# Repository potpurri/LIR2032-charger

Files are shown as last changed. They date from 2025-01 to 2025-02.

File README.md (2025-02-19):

# LIR2032 Battery Charging Board

## Overview

Charging board for LIR2032 batteries (or other lithium type button/coin cell batteries with the same diameter and max voltage of 4.2V).

This project features a charging board for LIR2032 batteries. It uses a TP4056 to monitor charging and provides options for safety components. The circuit includes components to manage the charging process efficiently and safely.

Completed PCBs:

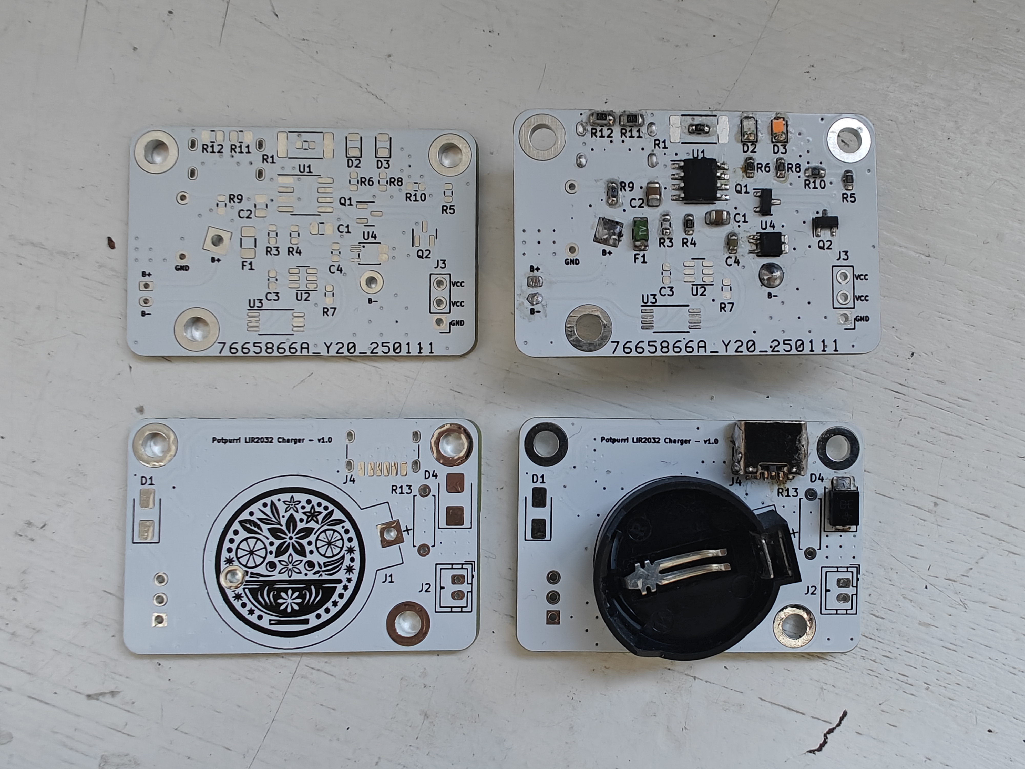
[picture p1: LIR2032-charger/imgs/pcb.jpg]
PCB


## Features

The board includes the following components:

- **TP4056**: For monitoring the charging process.
- **Safety options**: Can use either a DW01A and a FS8205A or a XB7608AJ for safety.
- **P-MOSFETs**: Two P-MOSFETs cut the connection between the battery and the load during charging (if a load is connected to the charging board).
- **Schottky Diode**: Available to forward current from the USB-C charging input to the load during charging.
- **Charging Current Settings (Resistor R9)**: The resistor R9 is used to set the charging current with the following correlations:

| Resistor (Ω) | Charging Current (mA) |
|---|---|
| 10k | 120 |
| 12k | 100 |
| 15k | 80.0 |
| 18k | 66.7 |
| 22k | 54.5 |
| 27k | 44.4 |
| 33k | 36.4 |
| 39k | 30.8 |
| 47k | 25.5 |
| 56k | 21.4 |
| 68k | 17.6 |
| 82k | 14.6 |
| 100k | 12.0 |

Board being charged with approximately 37mA:

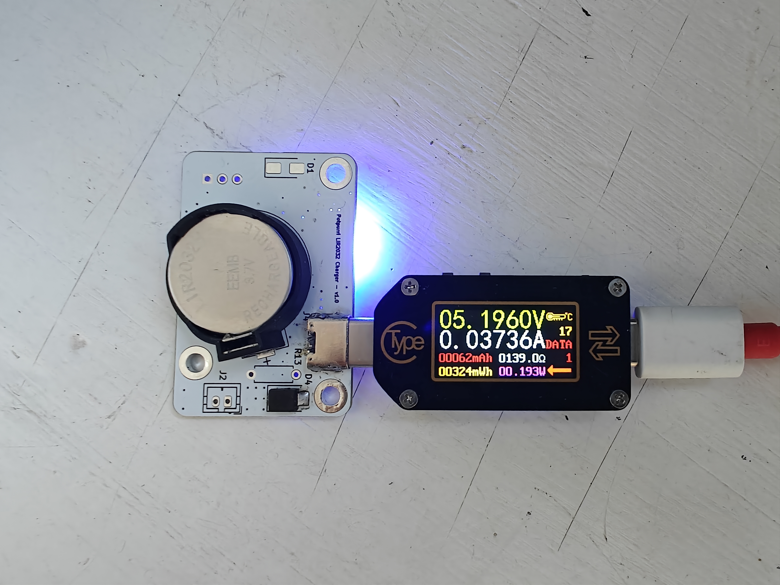
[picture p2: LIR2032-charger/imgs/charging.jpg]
Charging


## Images

Below are images of the PCB:

3D render of the front view of the PCB

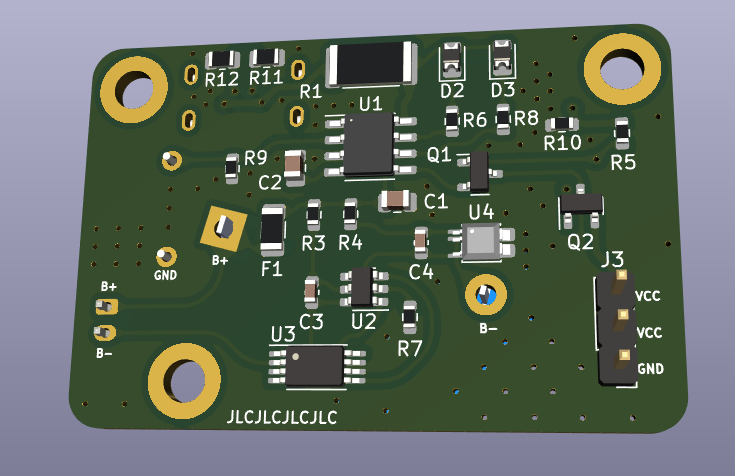
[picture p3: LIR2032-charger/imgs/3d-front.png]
3D Front


3D render of the back view of the PCB

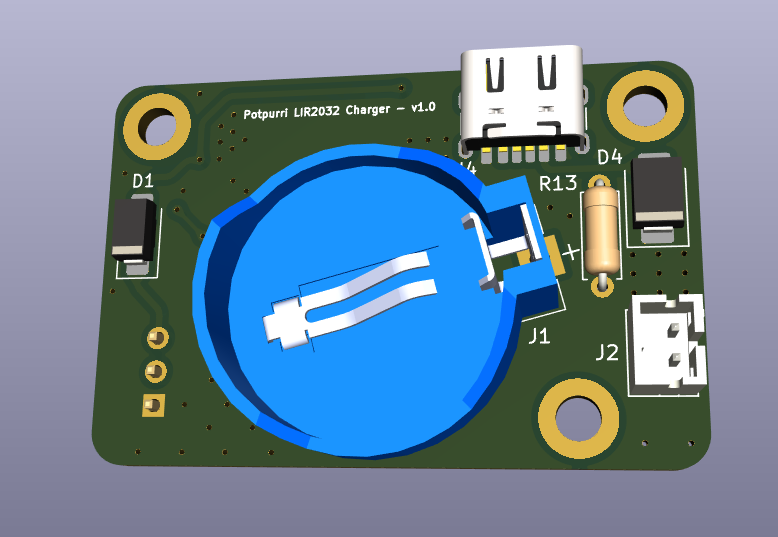
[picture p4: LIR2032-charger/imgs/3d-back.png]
3D Back


Front view of the actual PCB

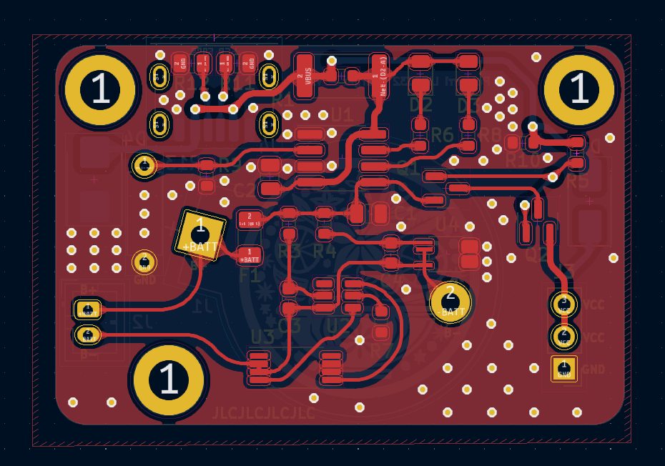
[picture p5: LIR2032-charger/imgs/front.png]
Front


Back view of the PCB

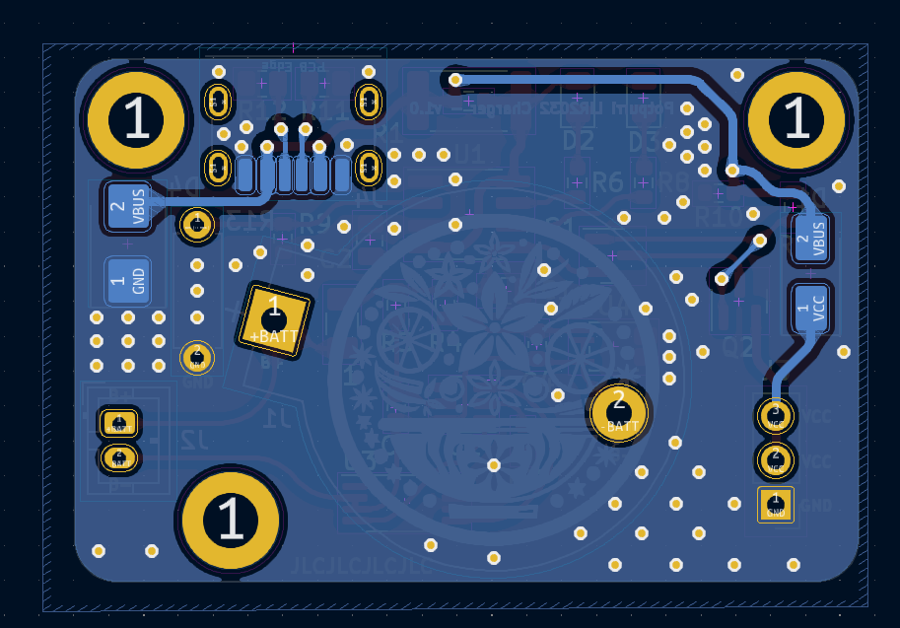
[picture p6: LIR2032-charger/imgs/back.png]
Back


## Schematics

For detailed schematics, please refer to the [schematic PDF](LIR2032-charger/imgs/schematic.pdf).

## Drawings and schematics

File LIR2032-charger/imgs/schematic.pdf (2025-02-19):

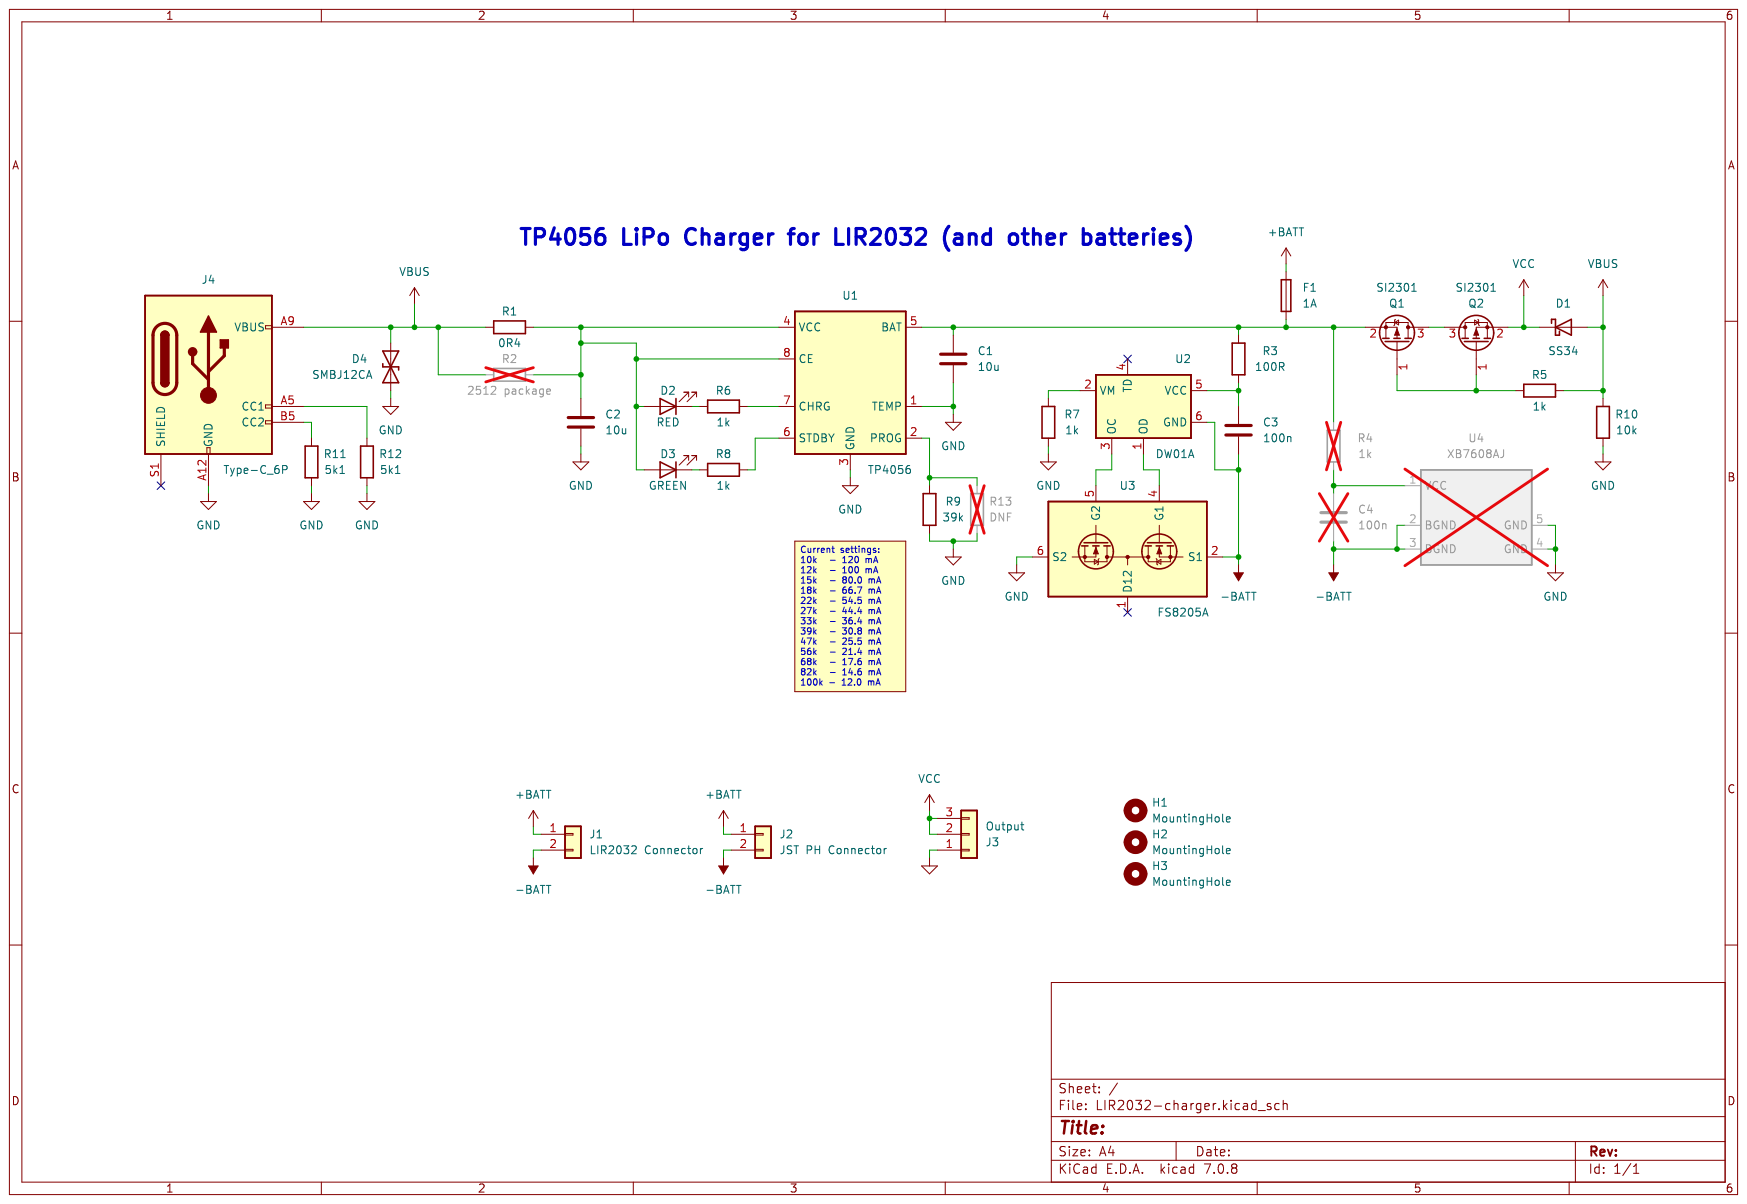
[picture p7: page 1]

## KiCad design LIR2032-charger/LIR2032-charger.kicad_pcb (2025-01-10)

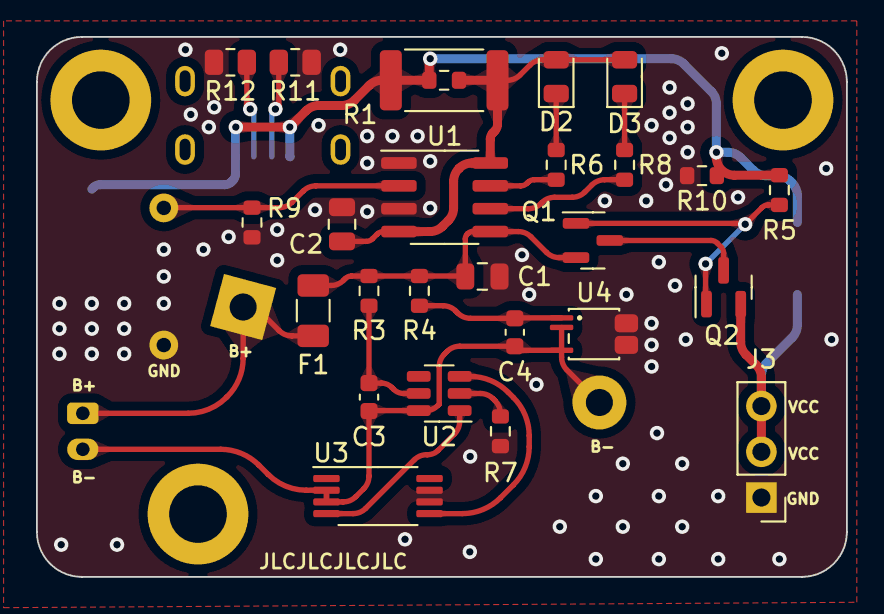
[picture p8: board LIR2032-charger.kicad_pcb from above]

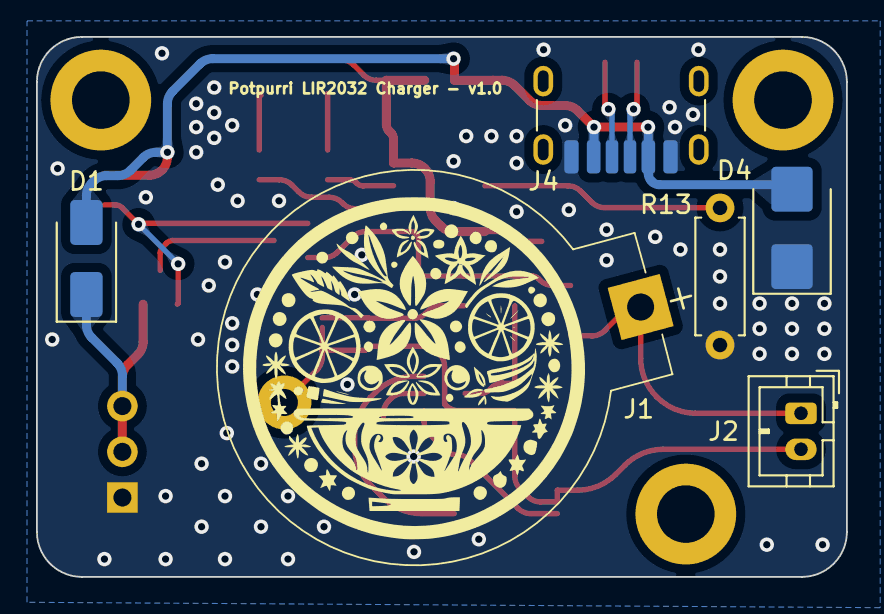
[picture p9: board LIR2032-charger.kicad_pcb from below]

Board: 2 copper layers, 45.0 x 30.0 mm, 35 parts (6 on the bottom side), 21 nets.

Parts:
C1, C2: 10u; C_0805_2012Metric
C3, C4: 100n; C_0603_1608Metric
D1: SS34; D_SMA
D2: RED; D_0805_2012Metric
D3: GREEN; D_0805_2012Metric
D4: SMBJ12CA; D_SMB
F1: 1A; Fuse_1206_3216Metric
H1, H2, H3: MountingHole; MountingHole_3.2mm_M3_DIN965_Pad
J1: LIR2032 Connector; CoinCell CR2032
J2: JST PH Connector; JST_PH_B2B-PH-K_1x02_P2.00mm_Vertical
J3: Output; PinHeader_1x03_P2.54mm_Vertical
J4: Type-C_6P; USB-C 6 Pin - Long pads
Q1, Q2: SI2301; SOT-23
R1: 0R4; R_0603_1608Metric
R2: 2512 package; R_2512_6332Metric
R3: 100R; R_0603_1608Metric
R4, R5, R6, R7, R8: 1k; R_0603_1608Metric
R9: 39k; R_0603_1608Metric
R10: 10k; R_0603_1608Metric
R11, R12: 5k1; R_0805_2012Metric
R13: DNF; R_Axial_DIN0207_L6.3mm_D2.5mm_P7.62mm_Horizontal
U1: TP4056; SOP-8_3.76x4.96mm_P1.27mm
U2: DW01A; SOT-23-6
U3: FS8205A; TSSOP-8_4.4x3mm_P0.65mm
U4: XB7608AJ; CPC-5

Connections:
+BATT: F1.1, J1.1, J2.1
-BATT: C3.2, C4.2, J1.2, J2.2, U2.6 (GND), U3.2 (S1), U3.3 (S1), U4.2 (BGND), U4.3 (BGND)
GND: C1.2, C2.2, D4.1 (A1), J3.1, J4.A12 (GND), J4.B12 (GND), R7.2, R9.2, R10.2, R11.2, R12.2, R13.2, U1.1 (TEMP), U1.3 (GND), U3.6 (S2), U3.7 (S2), U4.4 (GND), U4.5 (GND)
unnamed: C2.1, D2.2 (A), D3.2 (A), R1.1, R2.1, U1.4 (VCC), U1.8 (CE)
unnamed: D2.1 (K), R6.1
unnamed: D3.1 (K), R8.1
unnamed: J4.A5 (CC1), R12.1
unnamed: J4.B5 (CC2), R11.1
unnamed: Q1.3 (D), Q2.3 (D)
unnamed: Q1.1 (G), Q2.1 (G), R5.1
unnamed: C1.1, F1.2, Q1.2 (S), R3.2, R4.2, U1.5 (BAT)
unnamed: R6.2, U1.7 (CHRG)
unnamed: R9.1, R13.1, U1.2 (PROG)
unnamed: R8.2, U1.6 (STDBY)
unnamed: U2.3 (OC), U3.5 (G2)
unnamed: U2.1 (OD), U3.4 (G1)
unnamed: C3.1, R3.1, U2.5 (VCC)
unnamed: R7.1, U2.2 (VM)
unnamed: C4.1, R4.1, U4.1 (VCC)
VBUS: D1.2 (A), D4.2 (A2), J4.A9 (VBUS), J4.B9 (VBUS), R1.2, R2.2, R5.2, R10.1
VCC: D1.1 (K), J3.2, J3.3, Q2.2 (S)

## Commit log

2025-01-08 board layout
    [LIR2032-charger.kicad_pcb, LIR2032-charger.kicad_sch]
2025-01-10 Added manufacturing files
    [LIR2032-charger.kicad_pcb, LIR2032-charger.kicad_sch]
2025-02-19 added images and schematic
2025-02-19 added images of pcb
